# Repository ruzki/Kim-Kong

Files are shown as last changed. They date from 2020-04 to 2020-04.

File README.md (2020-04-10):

# Kim Kong
Daughterboard based on STM32F407VGT6 for the Speeduino ECU Project <br />
License <br />

<br />
This is a KiCad project of an Daughterboard to fit the kdFi by k-data.org (all rights reserved)  Motherboard Footprint.
Use most recent KiCad Nighty Build Version to open this project. 

This is not an k-data.org prouduct nor is it licencsed by k-data.org. 
You may contact k-data.org before using this Board on original k-data.org hardware and ask for permission.

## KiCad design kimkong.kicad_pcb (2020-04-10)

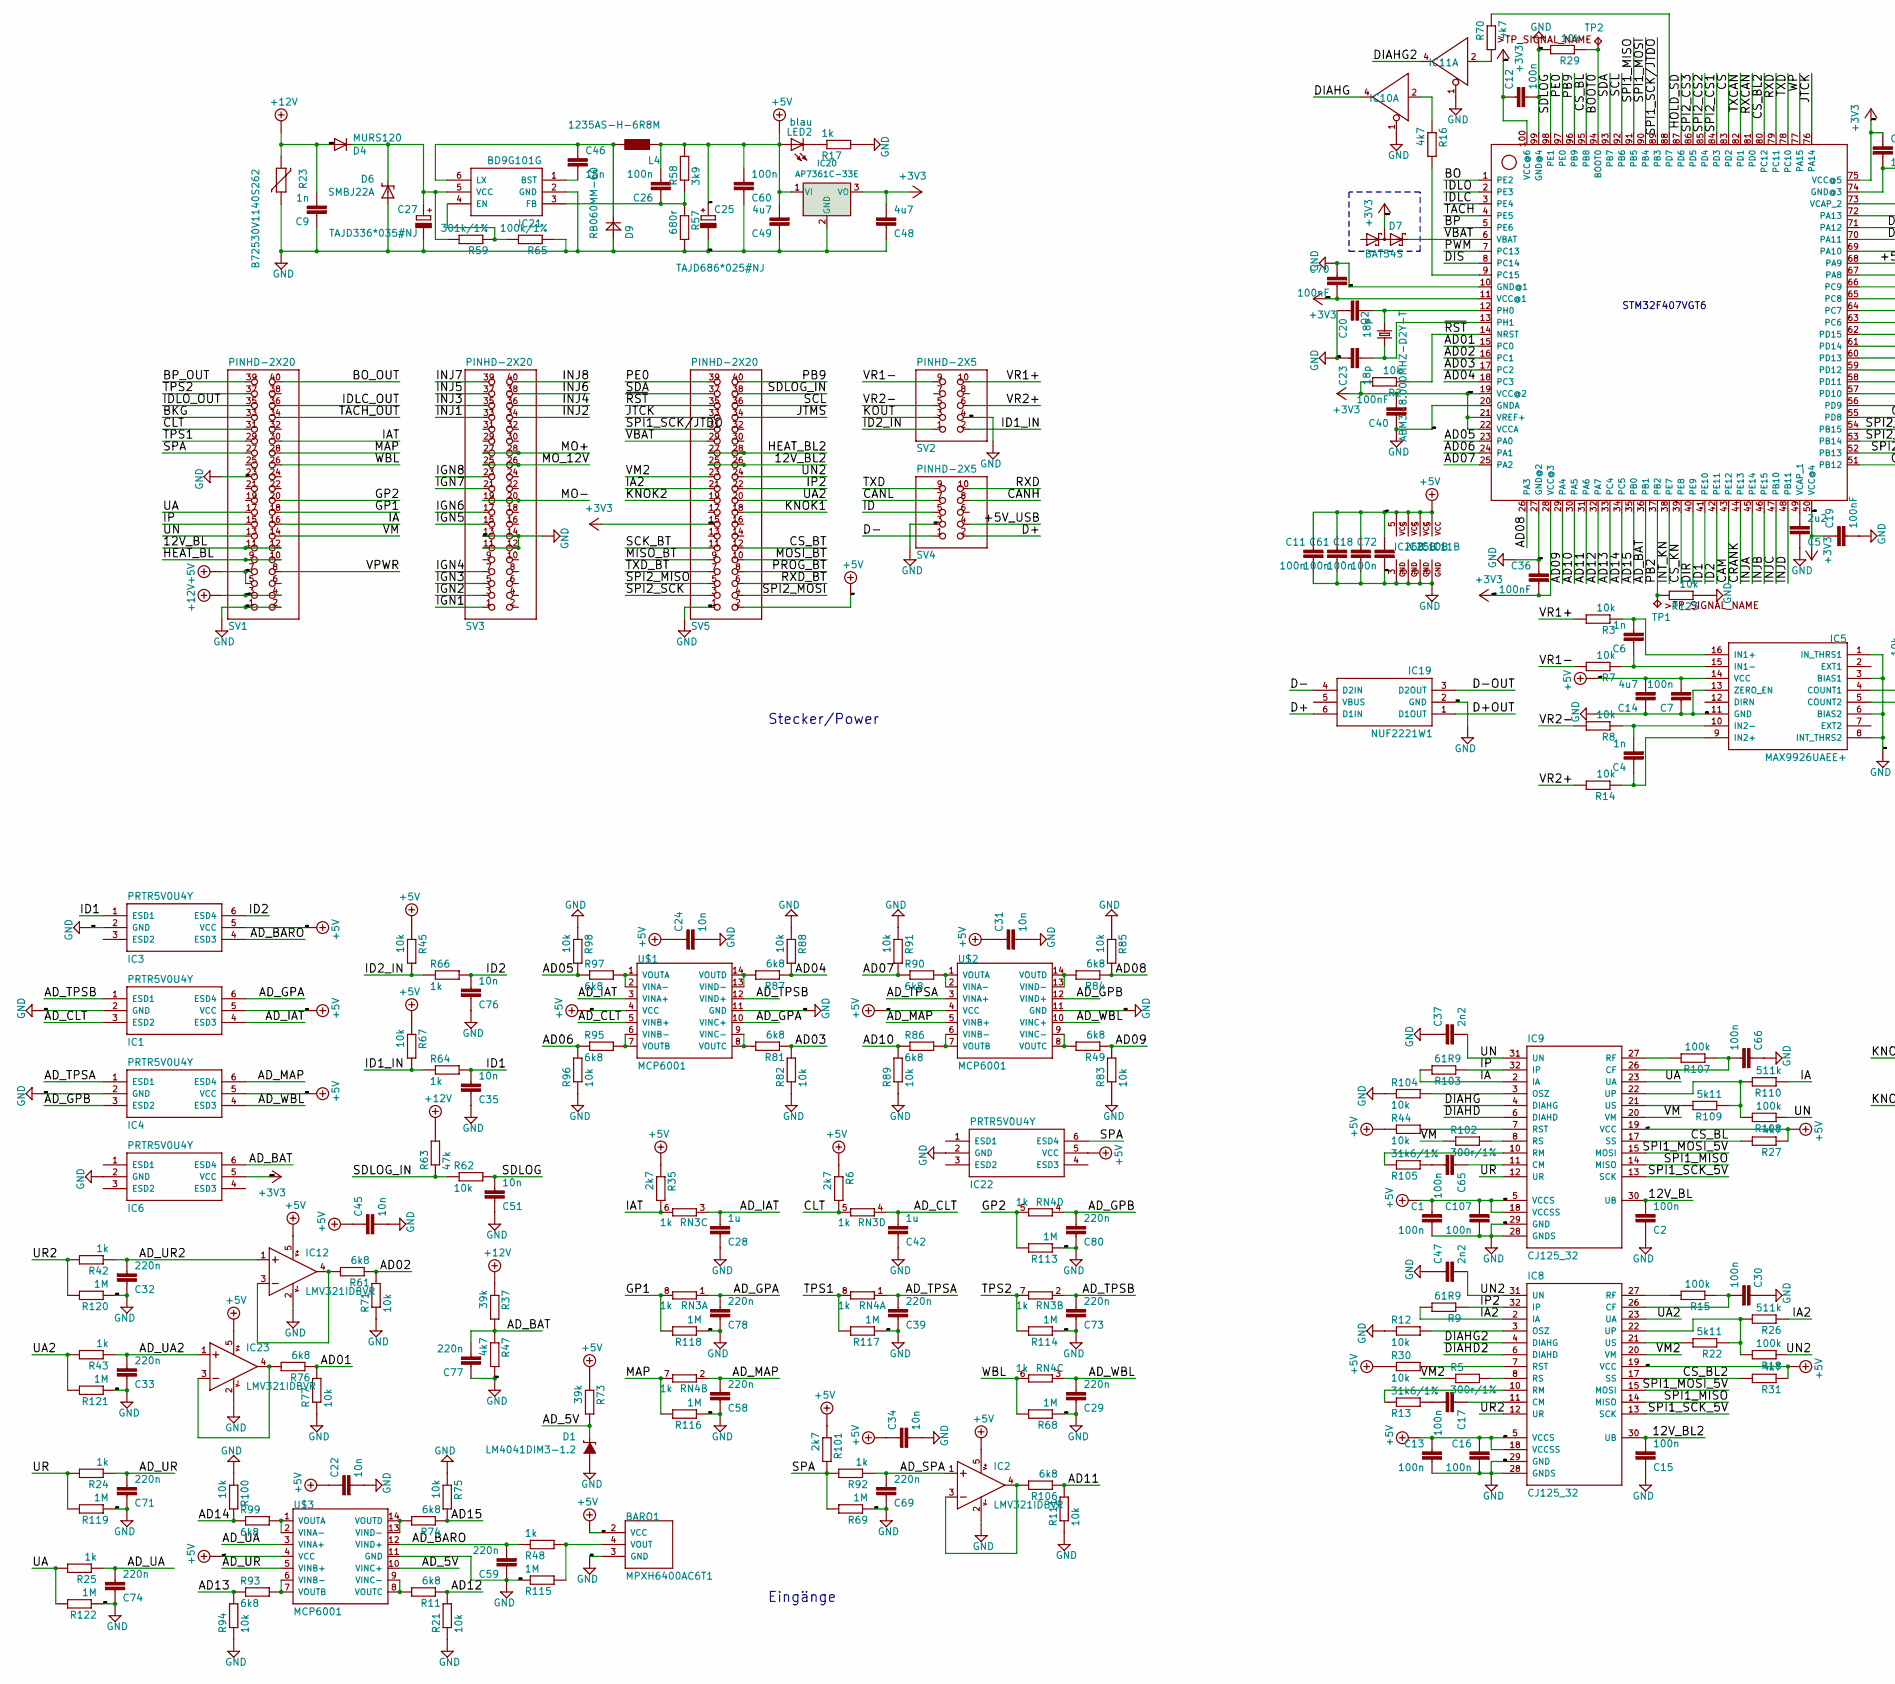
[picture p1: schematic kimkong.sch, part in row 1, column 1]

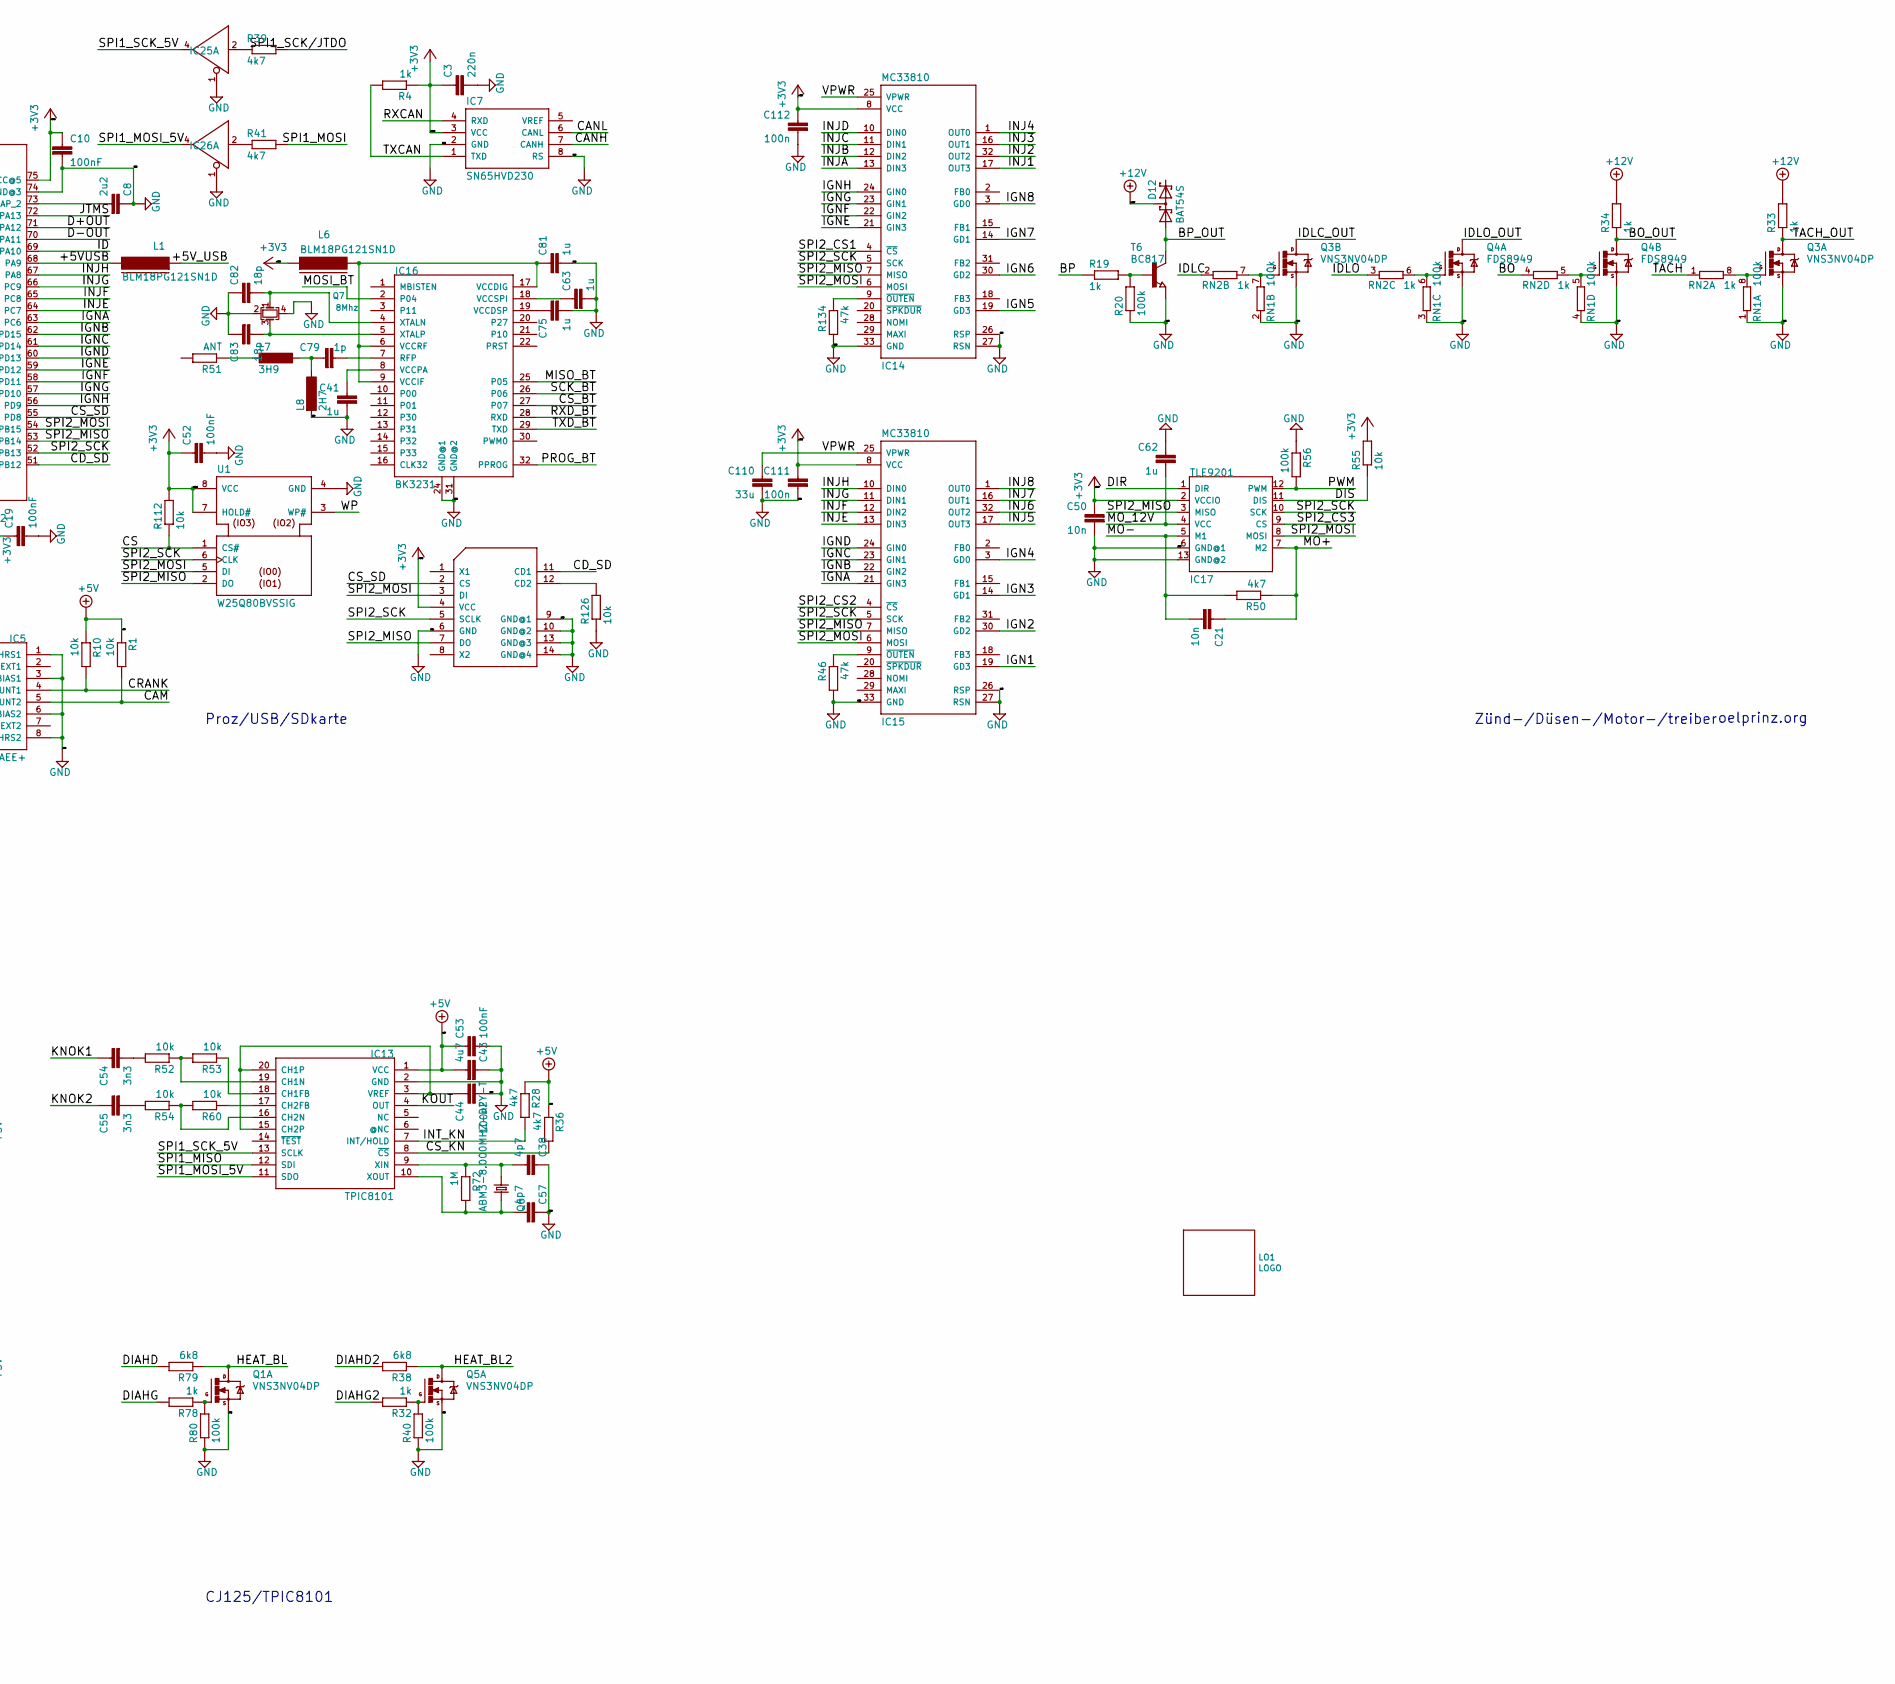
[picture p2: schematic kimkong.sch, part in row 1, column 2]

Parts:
BARO1: MPXH6400AC6T1; Case1317
C1, C2, C7, C11, C12, C13, C15, C16, C17, C18, C26, C30, C60, C61, C65, C66, C72, C107, C111, C112: 100n; C0603
C3, C29, C32, C33, C39, C58, C59, C69, C71, C73, C74, C77, C78, C80: 220n; C0603
C4, C6: 1n; C0603
C5, C8: 2u2; C0603
C9: 1n; C0805
C10, C19, C36, C40, C44, C52, C53, C70: 100nF; C0603
C14, C48, C49: 4u7; C0603
C20, C23, C82, C83: 18p; C0603
C21: 10n; C1206
C22, C24, C31, C34, C35, C45, C50, C51, C76: 10n; C0603
C25: TAJD686*025#NJ; SMC_D
C27: TAJD336*035#NJ; SMC_D
C28, C41, C42, C62, C63, C75, C81: 1u; C0603
C37, C47: 2n2; C0603
C38, C57: 4p7; C0603
C43: 4u7; C0805
C46: 15n; C0603
C54, C55: 3n3; C0603
C79: 1p; C0603
C110: 33u; C1206
D1: LM4041DIM3-1.2; DBZ_R-PDSO-G3
D4: MURS120
D6: SMBJ22A; SMBJ
D7, D12: BAT54S; SOT23
D9: RB060MM-60
IC1, IC3, IC4, IC6, IC22: PRTR5V0U4Y; SOT363_PHILIPS
IC2, IC12, IC23: LMV321IDBVR; SC70-5L
IC5: MAX9926UAEE+; QSOP16
IC7: SN65HVD230; SO8
IC8, IC9: CJ125_32; TQFP32-08
IC10, IC11, IC25, IC26: 741G125DCK; SC70-5
IC13: TPIC8101; SO-20LD
IC14, IC15: MC33810
IC16: BK3231; QFN-32
IC17: TLE9201
IC18: STM32F407VGT6; LQFP100
IC19: NUF2221W1; SOT363_PHILIPS
IC20: AP7361C-33E; SOT-89-5_Housing
IC21: BD9G101G; SSOT6
L1, L6: BLM18PG121SN1D; FB805
L4: 1235AS-H-6R8M
L7: 3H9; L2012C
L8: 2H7; L2012C
LED2: blau; SML0805
LO1: LOGO; KimKong_40x50
Q1, Q3, Q5: VNS3NV04DP; M08A
Q2, Q6: ABM3-8.000MHZ-D2Y-T; ABM3
Q4: FDS8949; M08A
Q7: 8Mhz; ABM11
R1, R2, R10, R12, R21, R29, R30, R44, R45, R52, R53, R54, R55, R60, R62, R67, R71, R75, R77, R82, R83, R85, R88, R89, R91, R94, R96, R98, R100, R104, R111, R112, R123, R126: 10k; R0603
R3, R7, R8, R14: 10k; R1206
R4, R17, R19, R24, R25, R32, R33, R34, R42, R43, R48, R64, R66, R78, R92: 1k; R0603
R5, R102: 300r/1%; R0603
R6, R35, R101: 2k7; R0603
R9, R103: 61R9; R0603
R11, R38, R49, R61, R74, R76, R79, R81, R84, R86, R87, R90, R93, R95, R97, R99, R106: 6k8; R0603
R13, R105: 31k6/1%; R0603
R15, R18, R20, R40, R56, R80, R107, R108: 100k; R0603
R16, R27, R28, R31, R36, R39, R41, R47, R70: 4k7; R0603
R22, R109: 5k11; R0603
R23: B72530V1140S262; CT_CN1210
R26, R110: 511k; R0603
R37, R73: 39k; R0603
R46, R63, R134: 47k; R0603
R50: 4k7; R1206
R51: ANT; 2450AT18A100E
R57: 680r; R0603
R58: 3k9; R0603
R59: 301k/1%; R0603
R65: 100k/1%; R0603
R68, R69, R72, R113, R114, R115, R116, R117, R118, R119, R120, R121, R122: 1M; R0603
RN1: 100k; 0603-ARV
RN2, RN3, RN4: 1k; 0603-ARV
SV1, SV3, SV5: PINHD-2X20; 2X20
SV2, SV4: PINHD-2X5; 2X05
T6: BC817; SOT23
TP1, TP2: TPTP13R; TP13R
U1: W25Q80BVSSIG; SO08W
U$1, U$2, U$3: MCP6001; TSSOP14
U$6: AMPHENOL_1140084168

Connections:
+3V3: C3.1, C10.1, C12.1, C19.1, C36.2, C40.2, C48.2, C50.1, C52.1, C70.2, C111.1, C112.1, D7.3 (C1A2), IC6.5 (VCC), IC7.3 (VCC), IC14.8 (VCC), IC15.8 (VCC), IC17.2 (VCCIO), IC18.11 (VCC@1), IC18.19 (VCC@2), IC18.21 (VREF+), IC18.22 (VCCA), IC18.28 (VCC@3), IC18.50 (VCC@4), IC18.75 (VCC@5), IC18.100 (VCC@6), IC20.3 (VO), L6.2, R2.2, R4.1, R55.2, R112.2, SV5.15, U1.7 (HOLD#), U1.8 (VCC), U$6.4 (VCC)
+5V: BARO1.2 (VCC), C1.1, C7.2, C11.1, C13.1, C14.2, C16.1, C18.1, C22.1, C24.1, C25.+, C26.2, C31.1, C34.1, C43.2, C45.1, C49.2, C53.1, C60.2, C61.1, C72.1, C107.1, IC1.5 (VCC), IC2.5 (V+), IC3.5 (VCC), IC4.5 (VCC), IC5.14 (VCC), IC8.5 (VCCS), IC8.18 (VCCSS), IC8.19 (VCC), IC9.5 (VCCS), IC9.18 (VCCSS), IC9.19 (VCC), IC10.5 (VCC), IC11.5 (VCC), IC12.5 (V+), IC13.1 (VCC), IC20.1 (VI), IC22.5 (VCC), IC23.5 (V+), IC25.5 (VCC), IC26.5 (VCC), L4.1, LED2.A, R1.1, R6.1, R10.1, R27.1, R28.1, R30.1, R31.1, R35.1, R36.1, R44.1, R45.1, R58.2, R67.1, R73.1, R101.1, SV1.5, SV1.7, SV5.2, U$1.4 (VCC), U$2.4 (VCC), U$3.4 (VCC)
+12V: C9.2, D4.1 (A), D12.3 (C1A2), R23.2, R33.2, R34.2, R37.1, R63.2, SV1.3, SV1.4
/12V_BL: C2.2, IC9.30 (UB), SV1.11, SV1.12
/12V_BL2: C15.2, IC8.30 (UB), SV5.25, SV5.26
/+5VUSB: IC18.68 (PA9), L1.1
/+5V_USB: L1.2, SV4.4
/AD01: IC18.15 (PC0), R76.1, R77.2
/AD02: IC18.16 (PC1), R61.1, R71.2
/AD03: IC18.17 (PC2), R81.1, R82.2
/AD04: IC18.18 (PC3), R87.1, R88.2
/AD05: IC18.23 (PA0), R97.1, R98.2
/AD06: IC18.24 (PA1), R95.1, R96.2
/AD07: IC18.25 (PA2), R90.1, R91.2
/AD08: IC18.26 (PA3), R84.1, R85.2
/AD09: IC18.29 (PA4), R49.1, R83.2
/AD10: IC18.30 (PA5), R86.1, R89.2
/AD11: IC18.31 (PA6), R106.1, R111.2
/AD12: IC18.32 (PA7), R11.1, R21.2
/AD13: IC18.33 (PC4), R93.1, R94.2
/AD14: IC18.34 (PC5), R99.1, R100.2
/AD15: IC18.35 (PB0), R74.1, R75.2
/AD_5V: D1.1 (C), R73.2, U$3.10 (VINC+)
/AD_BARO: C59.2, IC3.4 (ESD3), R48.1, U$3.12 (VIND+)
/AD_BAT: C77.2, IC6.6 (ESD4), IC18.36 (PB1), R37.2, R47.1
/AD_CLT: C42.2, IC1.3 (ESD2), RN3.4 (1), U$1.5 (VINB+)
/AD_GPA: C78.2, IC1.6 (ESD4), RN3.1, U$1.10 (VINC+)
/AD_GPB: C80.2, IC4.3 (ESD2), RN4.4 (1), U$2.12 (VIND+)
/AD_IAT: C28.2, IC1.4 (ESD3), RN3.3 (1), U$1.3 (VINA+)
/AD_MAP: C58.2, IC4.6 (ESD4), RN4.2 (1), U$2.5 (VINB+)
/AD_SPA: C69.2, IC2.1 (+IN), R92.1
/AD_TPSA: C39.2, IC4.1 (ESD1), RN4.1, U$2.3 (VINA+)
/AD_TPSB: C73.2, IC1.1 (ESD1), RN3.2 (1), U$1.12 (VIND+)
/AD_UA: C74.2, R25.1, U$3.3 (VINA+)
/AD_UA2: C33.2, IC23.1 (+IN), R43.1
/AD_UR: C71.2, R24.1, U$3.5 (VINB+)
/AD_UR2: C32.2, IC12.1 (+IN), R42.1
/AD_WBL: C29.2, IC4.4 (ESD3), RN4.3 (1), U$2.10 (VINC+)
/BKG: SV1.33
/BO: IC18.1 (PE2), RN2.4 (1)
/BOOT0: IC18.94 (BOOT0), R29.1, TP2.TP
/BO_OUT: Q4.5 (D), Q4.6 (D), R34.1, SV1.40
/BP: IC18.5 (PE6), R19.1
/BP_OUT: D12.1 (A1), SV1.39, T6.3 (C)
/CAM: IC5.5 (COUNT2), IC18.43 (PE12), R1.2
/CANH: IC7.7 (CANH), SV4.8
/CANL: IC7.6 (CANL), SV4.7
/CD_SD: IC18.51 (PB12), U$6.11 (CD1)
/CLT: R6.2, RN3.5 (2), SV1.31
/CRANK: IC5.4 (COUNT1), IC18.44 (PE13), R10.2
/CS: IC18.83 (PD2), R112.1, U1.1 (CS#)
/CS_BL: IC9.17 (SS), IC18.95 (PB8), R27.2
/CS_BL2: IC8.17 (SS), IC18.80 (PC12), R31.2
/CS_BT: IC16.27 (P07), SV5.12
/CS_KN: IC13.8 (~CS), IC18.39 (PE8), R36.2
/CS_SD: IC18.55 (PD8), U$6.2 (CS)
/D+: IC19.6 (D1IN), SV4.2
/D+OUT: IC18.71 (PA12), IC19.1 (D1OUT)
/D-: IC19.4 (D2IN), SV4.1
/D-OUT: IC18.70 (PA11), IC19.3 (D2OUT)
/DIAHD: IC9.6 (DIAHD), R79.2
/DIAHD2: IC8.6 (DIAHD), R38.2
/DIAHG: IC9.4 (DIAHG), IC10.4 (O), R78.2
/DIAHG2: IC8.4 (DIAHG), IC11.4 (O), R32.2
/DIR: IC17.1 (DIR), IC18.40 (PE9)
/DIS: IC17.11 (DIS), IC18.8 (PC14), R55.1
/GP1: R118.2, RN3.8 (2), SV1.18
/GP2: R113.2, RN4.5 (2), SV1.20
/HEAT_BL: Q1.7 (D), Q1.8 (D), R79.1, SV1.9, SV1.10
/HEAT_BL2: Q5.7 (D), Q5.8 (D), R38.1, SV5.27, SV5.28
/HOLD_SD: IC18.87 (PD6)
/IA: IC9.2 (IA), R103.2, R110.1, SV1.16
/IA2: IC8.2 (IA), R9.2, R26.1, SV5.21
/IAT: R35.2, RN3.6 (2), SV1.30
/ID: IC18.69 (PA10), SV4.5
/ID1: C35.2, IC3.1 (ESD1), IC18.41 (PE10), R64.2
/ID1_IN: R64.1, R67.2, SV2.2
/ID2: C76.2, IC3.6 (ESD4), IC18.42 (PE11), R66.2
/ID2_IN: R45.2, R66.1, SV2.1
/IDLC: IC18.3 (PE4), RN2.2 (1)
/IDLC_OUT: Q3.5 (D), Q3.6 (D), SV1.36
/IDLO: IC18.2 (PE3), RN2.3 (1)
/IDLO_OUT: Q4.7 (D), Q4.8 (D), SV1.35
/IGN1: IC15.19 (GD3), SV3.1
/IGN2: IC15.30 (GD2), SV3.3
/IGN3: IC15.14 (GD1), SV3.5
/IGN4: IC15.3 (GD0), SV3.7
/IGN5: IC14.19 (GD3), SV3.15
/IGN6: IC14.30 (GD2), SV3.17
/IGN7: IC14.14 (GD1), SV3.21
/IGN8: IC14.3 (GD0), SV3.23
/IGNA: IC15.21 (GIN3), IC18.63 (PC6)
/IGNB: IC15.22 (GIN2), IC18.62 (PD15)
/IGNC: IC15.23 (GIN1), IC18.61 (PD14)
/IGND: IC15.24 (GIN0), IC18.60 (PD13)
/IGNE: IC14.21 (GIN3), IC18.59 (PD12)
/IGNF: IC14.22 (GIN2), IC18.58 (PD11)
/IGNG: IC14.23 (GIN1), IC18.57 (PD10)
/IGNH: IC14.24 (GIN0), IC18.56 (PD9)
/INJ1: IC14.17 (OUT3), SV3.33
/INJ2: IC14.32 (OUT2), SV3.34
/INJ3: IC14.16 (OUT1), SV3.35
/INJ4: IC14.1 (OUT0), SV3.36
/INJ5: IC15.17 (OUT3), SV3.37
/INJ6: IC15.32 (OUT2), SV3.38
/INJ7: IC15.16 (OUT1), SV3.39
/INJ8: IC15.1 (OUT0), SV3.40
/INJA: IC14.13 (DIN3), IC18.45 (PE14)
/INJB: IC14.12 (DIN2), IC18.46 (PE15)
/INJC: IC14.11 (DIN1), IC18.47 (PB10)
/INJD: IC14.10 (DIN0), IC18.48 (PB11)
/INJE: IC15.13 (DIN3), IC18.64 (PC7)
/INJF: IC15.12 (DIN2), IC18.65 (PC8)
/INJG: IC15.11 (DIN1), IC18.66 (PC9)
/INJH: IC15.10 (DIN0), IC18.67 (PA8)
/INT_KN: IC13.7 (INT/HOLD), IC18.38 (PE7), R28.2
/IP: IC9.32 (IP), R103.1, SV1.15
/IP2: IC8.32 (IP), R9.1, SV5.22
/JTCK: IC18.76 (PA14), SV5.33
/JTMS: IC18.72 (PA13), SV5.34
/KNOK1: C54.1, SV5.18
/KNOK2: C55.1, SV5.19
/KOUT: IC13.4 (OUT), SV2.3
/MAP: R116.2, RN4.7 (2), SV1.28
/MISO_BT: IC16.25 (P05), SV5.9
/MO+: C21.1, IC17.7 (M2), R50.1, SV3.27, SV3.28
/MO-: C21.2, IC17.5 (M1), R50.2, SV3.19, SV3.20
/MOSI_BT: IC16.2 (P04), SV5.10
/MO_12V: C62.2, IC17.4 (VCC), SV3.25, SV3.26
/PB2: IC18.37 (PB2), R123.2, TP1.TP
/PB9: IC18.96 (PB9), SV5.40
/PE0: IC18.97 (PE0), SV5.39
/PROG_BT: IC16.32 (PPROG), SV5.8
/PWM: IC17.12 (PWM), IC18.7 (PC13), R56.2
/RXCAN: IC7.4 (RXD), IC18.81 (PD0)
/RXD: IC18.79 (PC11), SV4.10
/RXD_BT: IC16.28 (RXD), SV5.6
/SCK_BT: IC16.26 (P06), SV5.11
/SCL: IC18.92 (PB6), SV5.36
/SDA: IC18.93 (PB7), SV5.37
/SDLOG: C51.2, IC18.98 (PE1), R62.2
/SDLOG_IN: R62.1, R63.1, SV5.38
/SPA: IC22.6 (ESD4), R69.2, R92.2, R101.2, SV1.27
/SPI1_MISO: IC8.14 (MISO), IC9.14 (MISO), IC13.12 (SDI), IC18.91 (PB5)
/SPI1_MOSI: IC18.90 (PB4), R41.2
/SPI1_MOSI_5V: IC8.15 (MOSI), IC9.15 (MOSI), IC13.11 (SDO), IC26.4 (O)
/SPI1_SCK/JTDO: IC18.89 (PB3), R39.2, SV5.31
/SPI1_SCK_5V: IC8.13 (SCK), IC9.13 (SCK), IC13.13 (SCLK), IC25.4 (O)
/SPI2_CS1: IC14.4 (~CS), IC18.84 (PD3)
/SPI2_CS2: IC15.4 (~CS), IC18.85 (PD4)
/SPI2_CS3: IC17.9 (CS), IC18.86 (PD5)
/SPI2_MISO: IC14.7 (MISO), IC15.7 (MISO), IC17.3 (MISO), IC18.53 (PB14), SV5.5, U1.2 (DO), U$6.7 (DO)
/SPI2_MOSI: IC14.6 (MOSI), IC15.6 (MOSI), IC17.8 (MOSI), IC18.54 (PB15), SV5.4, U1.5 (DI), U$6.3 (DI)
/SPI2_SCK: IC14.5 (SCK), IC15.5 (SCK), IC17.10 (SCK), IC18.52 (PB13), SV5.3, U1.6 (CLK), U$6.5 (SCLK)
/TACH: IC18.4 (PE5), RN2.1
/TACH_OUT: Q3.7 (D), Q3.8 (D), R33.1, SV1.34
/TPS1: R117.2, RN4.8 (2), SV1.29
/TPS2: R114.2, RN3.7 (2), SV1.37
/TXCAN: IC7.1 (TXD), IC18.82 (PD1), R4.2
/TXD: IC18.78 (PC10), SV4.9
/TXD_BT: IC16.29 (TXD), SV5.7
/UA: IC9.23 (UA), R25.2, R122.2, SV1.17
/UA2: IC8.23 (UA), R43.2, R121.2, SV5.20
/UN: C37.2, IC9.31 (UN), R108.1, SV1.13
/UN2: C47.2, IC8.31 (UN), R18.1, SV5.24
/UR: IC9.12 (UR), R24.2, R119.2
/UR2: IC8.12 (UR), R42.2, R120.2
/VBAT: D7.2 (C2), IC18.6 (VBAT), SV5.29
/VM: IC9.20 (VM), R102.1, SV1.14
/VM2: IC8.20 (VM), R5.1, SV5.23
/VPWR: C110.1, IC14.25 (VPWR), IC15.25 (VPWR), SV1.8
/VR1+: R3.2, SV2.10
/VR1-: R7.2, SV2.9
/VR2+: R14.2, SV2.6
/VR2-: R8.2, SV2.5
/WBL: R68.2, RN4.6 (2), SV1.26
/WP: IC18.77 (PA15), U1.3 (WP#)
/~RST: IC18.14 (NRST), R2.1, SV5.35
GND: BARO1.3 (GND), C1.2, C2.1, C3.2, C5.1, C7.1, C8.1, C9.1, C10.2, C11.2, C12.2, C13.2, C14.1, C15.1, C16.2, C18.2, C19.2, C20.1, C22.2, C23.1, C24.2, C25.-, C27.-, C28.1, C29.1, C30.1, C31.2, C32.1, C33.1, C34.2, C35.1, C36.1, C37.1, C38.1, C39.1, C40.1, C41.2, C42.1, C43.1, C44.2, C45.2, C47.1, C48.1, C49.1, C50.2, C51.1, C52.2, C53.2, C57.1, C58.1, C59.1, C60.1, C61.2, C62.1, C63.2, C66.1, C69.1, C70.1, C71.1, C72.2, C73.1, C74.1, C75.2, C76.1, C77.1, C78.1, C80.1, C81.2, C82.1, C83.1, C107.2, C110.2, C111.2, C112.2, D1.2 (A), D6.A, D9.1, IC1.2 (GND), IC2.2 (V-), IC3.2 (GND), IC4.2 (GND), IC5.1 (IN_THRS1), IC5.3 (BIAS1), IC5.6 (BIAS2), IC5.8 (INT_THRS2), IC5.11 (GND), IC5.13 (ZERO_EN), IC6.2 (GND), IC7.2 (GND), IC7.8 (RS), IC8.28 (GNDS), IC8.29 (GND), IC9.28 (GNDS), IC9.29 (GND), IC10.1 (OE), IC10.3 (GND), IC11.1 (OE), IC11.3 (GND), IC12.2 (V-), IC13.2 (GND), IC14.26 (RSP), IC14.27 (RSN), IC14.33 (GND), IC15.26 (RSP), IC15.27 (RSN), IC15.33 (GND), IC16.24 (GND@1), IC16.31 (GND@2), IC17.6 (GND@1), IC17.13 (GND@2), IC18.10 (GND@1), IC18.20 (GNDA), IC18.27 (GND@2), IC18.74 (GND@3), IC18.99 (GND@4), IC19.2 (GND), IC20.2 (GND), IC21.2 (GND), IC22.2 (GND), IC23.2 (V-), IC25.1 (OE), IC25.3 (GND), IC26.1 (OE), IC26.3 (GND), L8.2, Q1.1 (S), Q3.1 (S), Q3.3 (S), Q4.1 (S), Q4.3 (S), Q5.1 (S), Q7.2, Q7.4, R12.1, R17.2, R20.1, R21.1, R23.1, R29.2, R40.1, R46.2, R47.2, R56.1, R57.2, R65.1, R68.1, R69.1, R71.1, R75.1, R77.1, R80.1, R82.1, R83.1, R85.1, R88.1, R89.1, R91.1, R94.1, R96.1, R98.1, R100.1, R104.1, R111.1, R113.1, R114.1, R115.1, R116.1, R117.1, R118.1, R119.1, R120.1, R121.1, R122.1, R123.1, R126.1, R134.2, RN1.1, RN1.2 (1), RN1.3 (1), RN1.4 (1), SV1.1, SV1.2, SV1.23, SV2.4, SV3.11, SV3.12, SV3.13, SV3.14, SV4.3, SV5.1, T6.2 (E), U1.4 (GND), U$1.11 (GND), U$2.11 (GND), U$3.11 (GND), U$6.6 (GND), U$6.9 (GND@1), U$6.10 (GND@2), U$6.13 (GND@3), U$6.14 (GND@4)
unnamed: BARO1.4 (VOUT), R48.2, R115.2
unnamed: C4.1, IC5.9 (IN2+), R14.1
unnamed: C4.2, IC5.10 (IN2-), R8.1
unnamed: C5.2, IC18.49 (VCAP_1)
unnamed: C6.1, IC5.15 (IN1-), R7.1
unnamed: C6.2, IC5.16 (IN1+), R3.1
unnamed: C8.2, IC18.73 (VCAP_2)
unnamed: C17.1, IC8.11 (CM)
unnamed: C17.2, R13.2
unnamed: C20.2, IC18.12 (PH0), Q2.1
unnamed: C23.2, IC18.13 (PH1), Q2.2
unnamed: C26.1, IC21.3 (FB), R57.1, R58.1
unnamed: C27.+, D4.2 (C), D6.C, IC21.5 (VCC), R59.2
unnamed: C30.2, IC8.26 (CF), R15.1
unnamed: C38.2, IC13.9 (XIN), Q6.2, R72.1
unnamed: C41.1, IC16.8 (VCCPA)
unnamed: C44.1, IC13.3 (VREF), IC13.15 (CH2P), IC13.20 (CH1P)
unnamed: C46.1, D9.2, IC21.6 (LX), L4.2
unnamed: C46.2, IC21.1 (BST)
unnamed: C54.2, R52.2
unnamed: C55.2, R54.2
unnamed: C57.2, IC13.10 (XOUT), Q6.1, R72.2
unnamed: C63.1, IC16.18 (VCCSPI)
unnamed: C65.1, IC9.11 (CM)
unnamed: C65.2, R105.2
unnamed: C66.2, IC9.26 (CF), R107.1
unnamed: C75.1, IC16.19 (VCCDSP)
unnamed: C79.1, L7.1, L8.1
unnamed: C79.2, IC16.7 (RFP)
unnamed: C81.1, IC16.6 (VCCRF), IC16.9 (VCCIF), IC16.17 (VCCDIG), L6.1
unnamed: C82.2, IC16.4 (XTALN), Q7.1
unnamed: C83.2, IC16.5 (XTALP), Q7.3
unnamed: IC2.3 (-IN), IC2.4 (OUT), R106.2
unnamed: IC8.3 (OSZ), R12.2
unnamed: IC8.7 (RST), R30.2
unnamed: IC8.8 (RS), R5.2
unnamed: IC8.10 (RM), R13.1
unnamed: IC8.21 (US), R22.2
unnamed: IC8.22 (UP), R18.2, R22.1, R26.2
unnamed: IC8.27 (RF), R15.2
unnamed: IC9.3 (OSZ), R104.2
unnamed: IC9.7 (RST), R44.2
unnamed: IC9.8 (RS), R102.2
unnamed: IC9.10 (RM), R105.1
unnamed: IC9.21 (US), R109.2
unnamed: IC9.22 (UP), R108.2, R109.1, R110.2
unnamed: IC9.27 (RF), R107.2
unnamed: IC10.2 (I), R16.1
unnamed: IC11.2 (I), R70.2
unnamed: IC12.3 (-IN), IC12.4 (OUT), R61.2
unnamed: IC13.16 (CH2N), R54.1, R60.2
unnamed: IC13.17 (CH2FB), R60.1
unnamed: IC13.18 (CH1FB), R53.1
unnamed: IC13.19 (CH1N), R52.1, R53.2
unnamed: IC14.9 (~OUTEN), R134.1
unnamed: IC15.9 (~OUTEN), R46.1
unnamed: IC18.9 (PC15), R16.2
unnamed: IC18.88 (PD7), R70.1
unnamed: IC21.4 (EN), R59.1, R65.2
unnamed: IC23.3 (-IN), IC23.4 (OUT), R76.2
unnamed: IC25.2 (I), R39.1
unnamed: IC26.2 (I), R41.1
unnamed: L7.2, R51.1
unnamed: LED2.C, R17.1
unnamed: Q1.2 (G), R78.1, R80.2
unnamed: Q3.2 (G), RN1.8 (2), RN2.8 (2)
unnamed: Q3.4 (G), RN1.7 (2), RN2.7 (2)
unnamed: Q4.2 (G), RN1.6 (2), RN2.6 (2)
unnamed: Q4.4 (G), RN1.5 (2), RN2.5 (2)
unnamed: Q5.2 (G), R32.1, R40.2
unnamed: R11.2, U$3.8 (VOUTC), U$3.9 (VINC-)
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

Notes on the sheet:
Stecker/Power
Eingänge
CJ125/TPIC8101
Proz/USB/SDkarte
STM32F407VGT6
Zünd-/Düsen-/Motor-/treiber
oelprinz.org

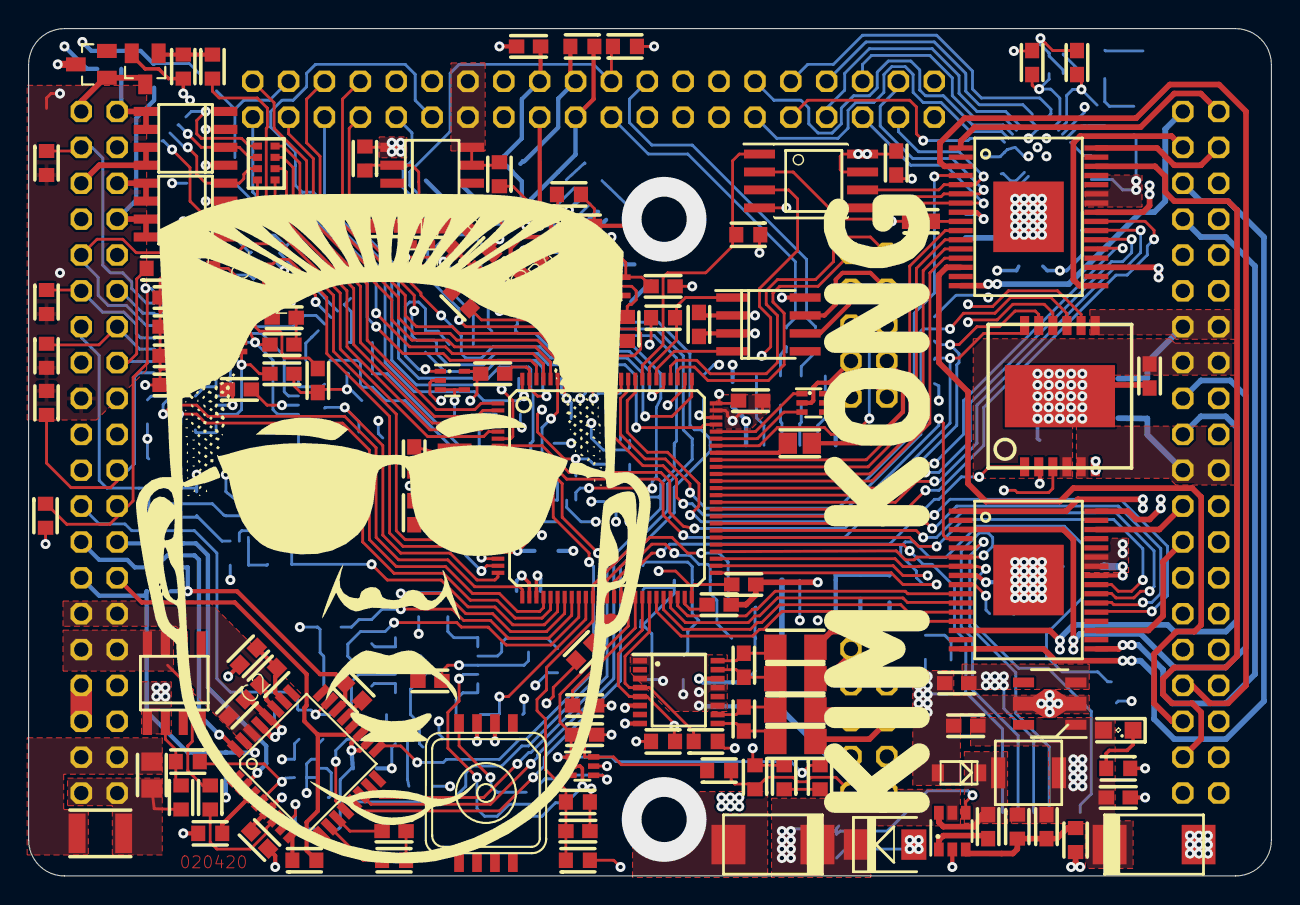
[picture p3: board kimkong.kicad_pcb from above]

Board: 4 copper layers, 88.0 x 60.0 mm, 271 parts (0 on the bottom side), 261 nets.

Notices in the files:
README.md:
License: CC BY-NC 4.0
